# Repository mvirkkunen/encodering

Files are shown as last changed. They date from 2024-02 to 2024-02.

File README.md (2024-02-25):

encodering (unfinished - the firmware for one has never even been run)
======================================================================

Yet another LED ring for encoders.

Features (once finished):

- LEDs in a ring (30 by default - but the LED layout is autogenerated)
- Handles encoder signals, presents simple counter register
- Multiple styles of ring display, automatically updated based on counter
- I2C based communication saving pins on your microcontroller
- Interrupt output pin
- Analog voltage output for simulated potentiometer

I2C protocol
------------

Write access:

- Write: [register] [data] [data...]

Read access:

- Write: [register]
- Read: [data] [data...]

Register pointer is auto-incremented.

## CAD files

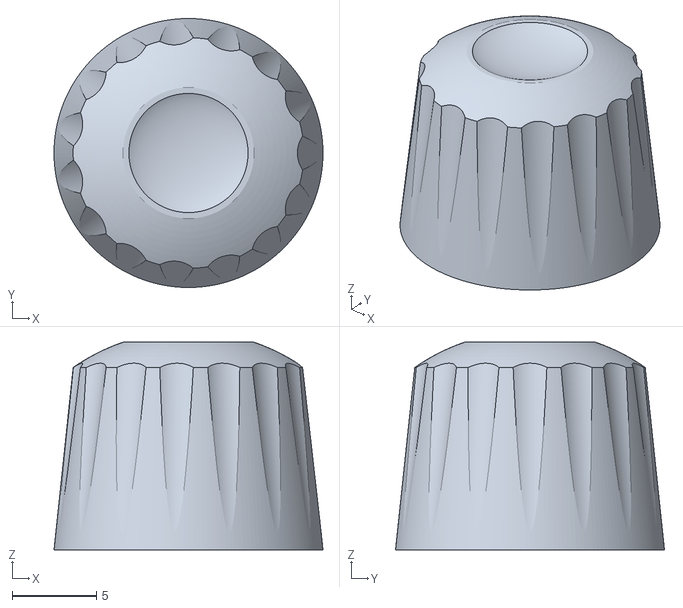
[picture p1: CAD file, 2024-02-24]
knob.stl
16.0 x 16.0 x 12.3

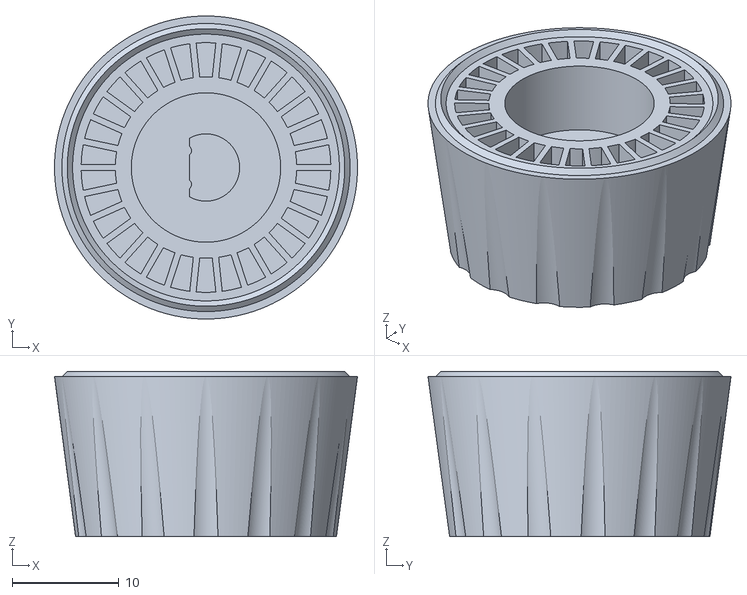
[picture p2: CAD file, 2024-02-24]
led_knob.stl
28.4 x 28.4 x 15.5

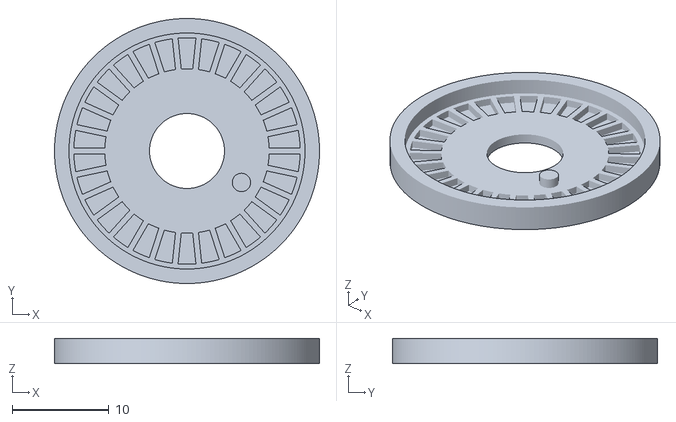
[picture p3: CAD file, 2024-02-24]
cover.stl
27.4 x 27.4 x 2.60

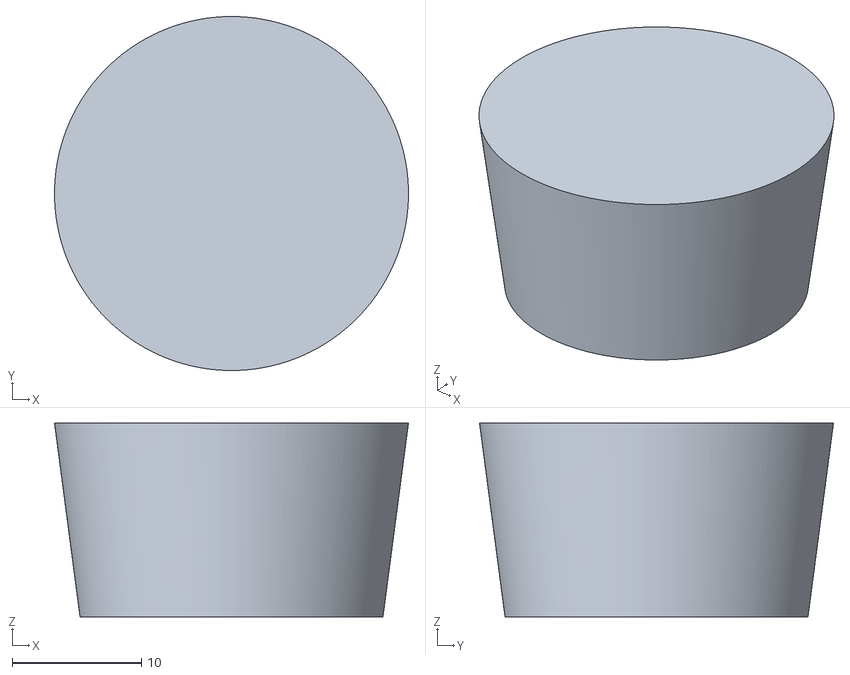
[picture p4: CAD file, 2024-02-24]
just_knob_envelope.stl
27.4 x 27.4 x 15.0

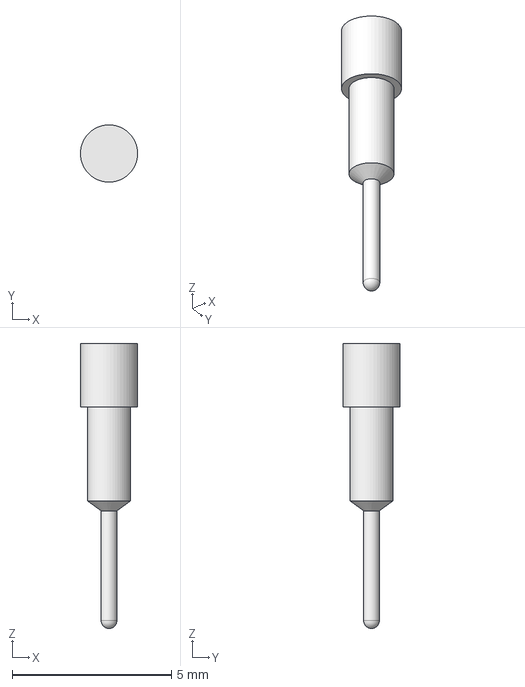
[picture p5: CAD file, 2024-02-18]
Connfly_DS-1006-11_No_Pin.FCStd
1.80 x 1.80 x 8.96 mm

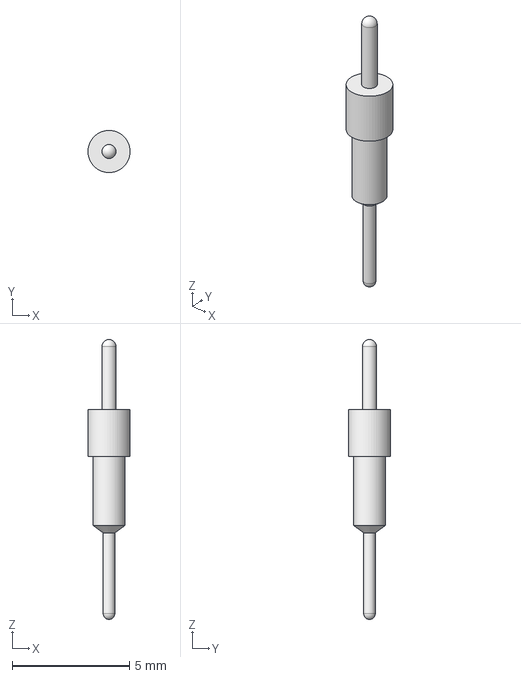
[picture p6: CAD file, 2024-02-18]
Connfly_DS-1006-11.FCStd
1.80 x 1.80 x 12.0 mm

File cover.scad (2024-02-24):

$fn = 180;

outer_diam = 24.4;
hole_diam = 7.75;
ring_r = 10;

alignment_hole_r = 6.5;
alignment_hole_a = 30;

wall_t = 1.5;

difference() {
  union() {
    difference() {
      cylinder(d=outer_diam + wall_t * 2, h=1 + 1.6);
      translate([0, 0, 0.25]) cylinder(d=outer_diam - 1, h=10);
      translate([0, 0, 1]) cylinder(d=outer_diam, h=10);
    }
    for (a = [0 : 360/30 : 360]) {
      rotate([0, 0, a]) translate([0, -0.3, 0]) cube([outer_diam/2, 0.6, 1]);
    }
    cylinder(r=ring_r - 1.5, h=1);
    rotate([0, 0, -alignment_hole_a]) translate([alignment_hole_r, 0, 0]) cylinder(d=1.9, h=1+1);
  }
  translate([0, 0, -1]) cylinder(d=hole_diam, h=10);
}

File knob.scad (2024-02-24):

$fn = 180;

diam = 16;
angle = 6;
height = 13;
knurls = 15;
knurl_r = 2.0;
knurl_angle = 8.0;
knurl_z = -0.3;
cap_r = 12;

shaft_d = 6.0 + 0.3;
shaft_d_t = 4.5;

d_interference = 0.2;

module knob() {
  intersection() {
    difference() {
      union() {
        difference() {
          cylinder(d1=diam, d2=diam - tan(angle) * height * 2, h=height);
          for (i = [0 : knurls]) {
            rotate([0, 0, 360/knurls * i])
              translate([diam/2 + knurl_r - -0.1, 0, knurl_z])
                rotate([0, -knurl_angle, 0]) cylinder(r=knurl_r , h=height*2);
          }
          
          translate([0, 0, -0.01]) difference() {
            cylinder(d=shaft_d, h=height - 2);
            translate([-shaft_d/2+shaft_d_t + d_interference, -shaft_d, -0.01])
              cube([shaft_d, shaft_d * 2, height]);
          }
        }
        
        translate([-shaft_d/2+shaft_d_t + 0.5, -shaft_d * 0.25, 0]) cylinder(d=1, h=height);
        translate([-shaft_d/2+shaft_d_t + 0.5, +shaft_d * 0.25, 0]) cylinder(d=1, h=height);
      }
      
      translate([0, 0, -0.1]) cylinder(d=diam - 3, h=4);
      
      translate([0, 0, height]) scale([4, 4, 1.4]) sphere(r=1);
      
      translate([0, 0, height - 0.65]) cylinder(d=diam, h=height);
    }
    hull() {
      translate([0, 0, height - cap_r]) sphere(r=cap_r);
      translate([0, 0, -height*2]) sphere(r=cap_r);
    }
  }
}

knob();

//intersection() { knob(); translate([-50, 0, -50]) cube([100, 100, 100]);  }

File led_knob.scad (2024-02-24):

$fn = $preview ? 45: 180;
E = 0.001;

module pcb_assembly() {
  color("green") translate([0, 0, -4.7 -1.6]) {
    difference() {
      rotate([0, 180, 0]) import("pcb_assembly.stl", convexity=5);
      /*translate([0, 0, -20]) union() {
        cylinder(d = 30, h=20 + 4.5+1.6);
        cylinder(d = 8, h=50);
      }*/
      translate([0, 0, 19]) cylinder(d=40, h=50);
    }
  }
  
  color("grey") translate([0, 0, 1.2]) {
    difference() {
      cylinder(d=11, h=2, $fn=6);
      translate([0, 0, -E]) cylinder(d=7.75, h=3);
    }
  }
}

leds = 30;
angle_step = 360 / leds;
outer_diam = 24 + 0.4;
hole_diam = 7.25;
ring_r = 10;
wall_t = 2;
led_h = 1.3;
knob_height = 15;
mizo_r = outer_diam * 0.5 + 0.8;

module led_separators(h) {
  for (a = [0 : angle_step : 360]) {
    rotate([0, 0, a]) translate([0, -0.3, 0]) cube([outer_diam/2, 0.6, h]);
  }
}

module plate() {
  alignment_hole_r = 6.5;
  alignment_hole_a = 30;

  difference() {
    union() {
      translate([0, 0, -1.6]) difference() {
        cylinder(d=outer_diam + wall_t * 2, h=led_h + 1.6);
        translate([0, 0, -E]) cylinder(d=outer_diam - 1, h=10);
      }
      cylinder(r=ring_r - 1.5, h=led_h);
      led_separators(led_h);
      
      rotate([0, 0, alignment_hole_a])
        translate([alignment_hole_r, 0, -1.2]) cylinder(d=1.9, h=1.2);
    }
    
    translate([0, 0, -1]) cylinder(d=hole_diam, h=10);
    
    translate([0, 0, 1.6])
      rotate_extrude()
        translate([mizo_r, 0])
          polygon([[-1, 0], [1, 0], [0, -1]]);
  }
}

module knob_envelope(d=0) {
  angle = 7.5;
  
  diam = outer_diam + wall_t * 2 + d;
  dd = tan(angle) * knob_height;
  cylinder(d1=diam, d2=diam - dd * 2, h=knob_height);
}

module knob() {
  diam = outer_diam + wall_t * 2;
  height = knob_height;
  knurls = 15;
  knurl_r = 2.0;
  knurl_angle = 5;
  knurl_z = -10.0;

  shaft_d = 6.0 + 0.3;
  shaft_d_t = 4.5;

  d_interference = 0.2;
  
  difference() {
    union() {
      difference() {
        union() {
          difference() {
            knob_envelope();
            translate([0, 0, -E]) cylinder(d=outer_diam - 1, h=$preview ? height + 1 : height - 0.24 + E);
          }
      
          led_separators(height);
          cylinder(r=ring_r - 1.5, h=height);
        }
        
        translate([0, 0, -0.01]) difference() {
          cylinder(d=shaft_d, h=height - 1);
          translate([-shaft_d/2+shaft_d_t + d_interference, -shaft_d, -0.01])
            cube([shaft_d, shaft_d * 2, height]);
        }
      }
      
      translate([-shaft_d/2+shaft_d_t + 0.5, -shaft_d * 0.25, 0]) cylinder(d=1, h=height);
      translate([-shaft_d/2+shaft_d_t + 0.5, +shaft_d * 0.25, 0]) cylinder(d=1, h=height);
      
      translate([0, 0, 0.5])
        rotate_extrude()
          translate([mizo_r, 0])
            polygon([[-1, 0], [1, 0], [0, -1]]);
    }
    
    translate([0, 0, -0.1]) cylinder(d=14, h=7);
    
    for (i = [0 : knurls]) {
      rotate([0, 0, 360/knurls * i + angle_step / 2])
        translate([diam/2 + knurl_r - -0.1, 0, knurl_z])
          rotate([0, -knurl_angle, 0]) cylinder(r=knurl_r , h=height*2);
    }
  }
}

module cutter() {
  translate([-50, 1, -50]) cube([100, 100, 100]);
}

if ($preview) {
  render() intersection() { cutter(); plate(); }
  intersection() { cutter(); translate([0, 0, 1.4]) rotate([0, 0, 180]) knob(); }

  pcb_assembly();
} else {
  //translate([outer_diam + 5, 0, led_h]) rotate([0, 180, 0]) plate();
  translate([0, 0, knob_height]) rotate([0, 180, 0]) knob();
  //translate([0, 0, knob_height]) rotate([0, 180, 0]) knob_envelope(-1);
}

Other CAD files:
just_knob.stl

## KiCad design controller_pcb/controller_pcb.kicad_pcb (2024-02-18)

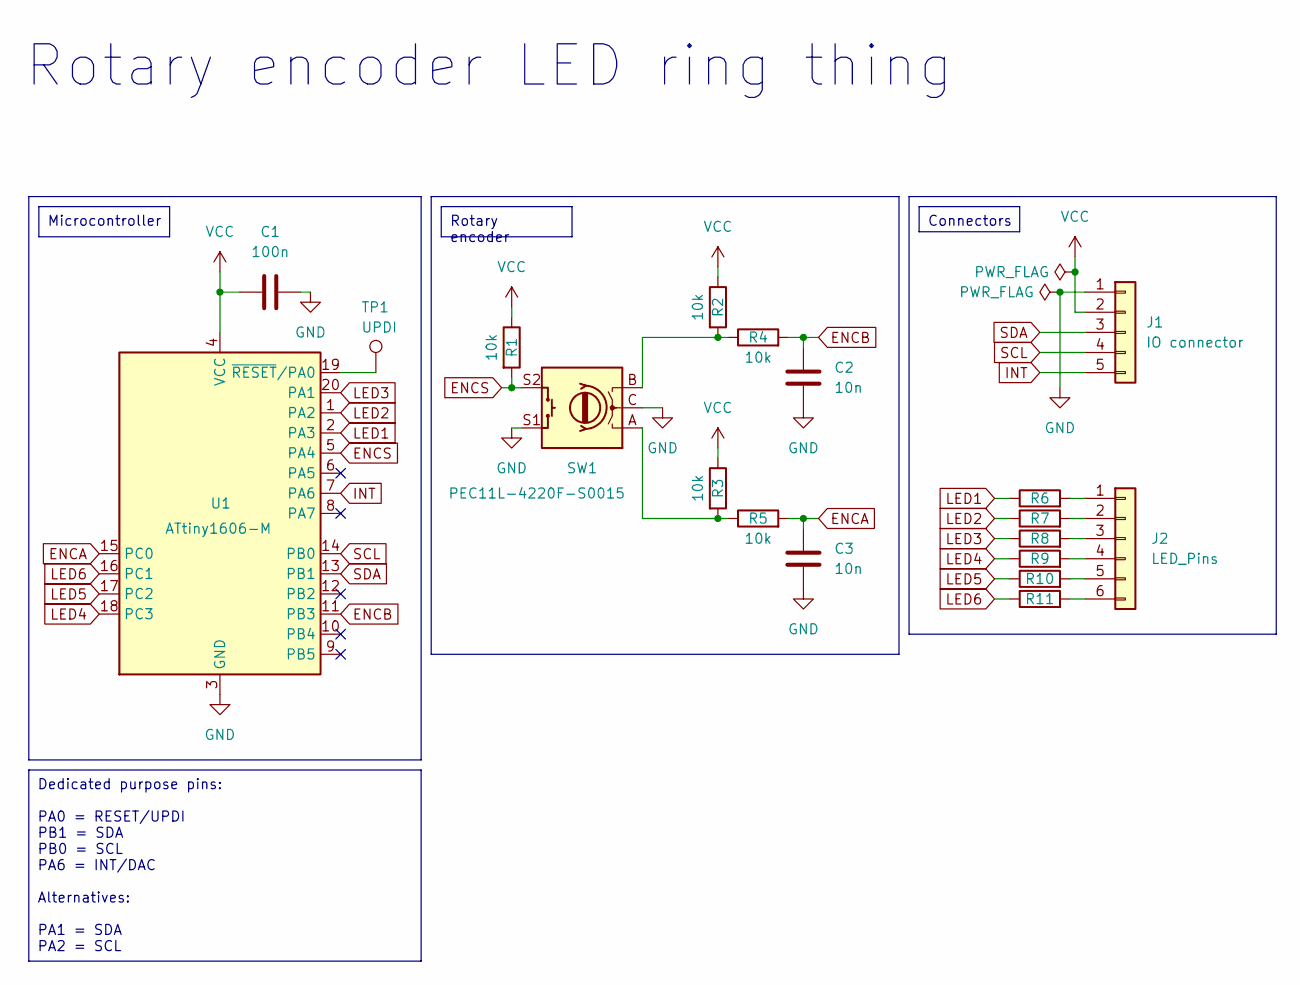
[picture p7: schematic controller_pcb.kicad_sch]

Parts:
C1: 100n; C_0603_1608Metric; LCSC C14663
C2, C3: 10n; C_0603_1608Metric; LCSC C57112
J1: IO connector; Project_PinHeader_1x05_P2.54mm_Vertical
J2: LED_Pins; Mounting_Hole_Pattern
R1, R2, R3, R4, R5: 10k; R_0603_1608Metric; LCSC C25804
R6, R7, R8, R9, R10, R11: 20ohm; R_0603_1608Metric; LCSC C22950
SW1: PEC11L-4220F-S0015; Project_RotaryEncoder_Bourns_Vertical_PEC12R-3x17F-Sxxxx
TP1: UPDI; TestPoint_Pad_D1.0mm
U1: ATtiny1606-M; Project_ATTINY1616_VQFN-20-1EP_3x3mm_P0.4mm_EP1.7x1.7mm; LCSC C507118

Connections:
ENCA: C3.2, R5.2, U1.15 (PC0)
ENCB: C2.2, R4.2, U1.11 (PB3)
ENCS: R1.2, SW1.S2, U1.5 (PA4)
GND: C1.2, C2.1, C3.1, J1.1, SW1.C, SW1.S1, U1.3 (GND), U1.21 (GND)
INT: J1.5, U1.7 (PA6)
LED1: R6.1, U1.2 (PA3)
LED2: R7.1, U1.1 (PA2)
LED3: R8.1, U1.20 (PA1)
LED4: R9.1, U1.18 (PC3)
LED5: R10.1, U1.17 (PC2)
LED6: R11.1, U1.16 (PC1)
unnamed: J2.1, R6.2
unnamed: J2.2, R7.2
unnamed: J2.3, R8.2
unnamed: J2.4, R9.2
unnamed: J2.5, R10.2
unnamed: J2.6, R11.2
unnamed: R2.2, R4.1, SW1.B
unnamed: R3.2, R5.1, SW1.A
unnamed: TP1.1, U1.19 (~RESET/PA0)
SCL: J1.4, U1.14 (PB0)
SDA: J1.3, U1.13 (PB1)
VCC: C1.1, J1.2, R1.1, R2.1, R3.1, U1.4 (VCC)

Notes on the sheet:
Microcontroller
Dedicated purpose pins: PA0 = RESET/UPDI PB1 = SDA PB0 = SCL PA6 = INT/DAC Alternatives: PA1 = SDA PA2 = SCL
Rotary encoder
Connectors
Rotary encoder LED ring thing

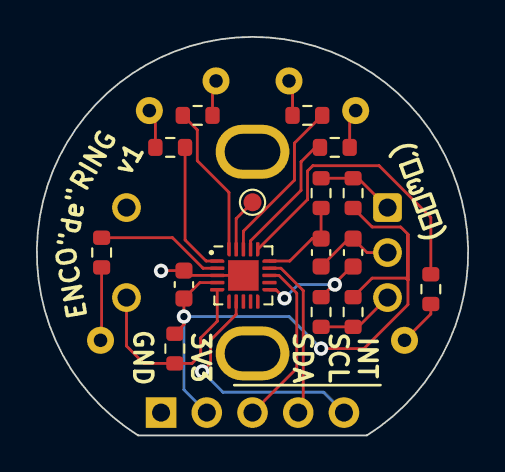
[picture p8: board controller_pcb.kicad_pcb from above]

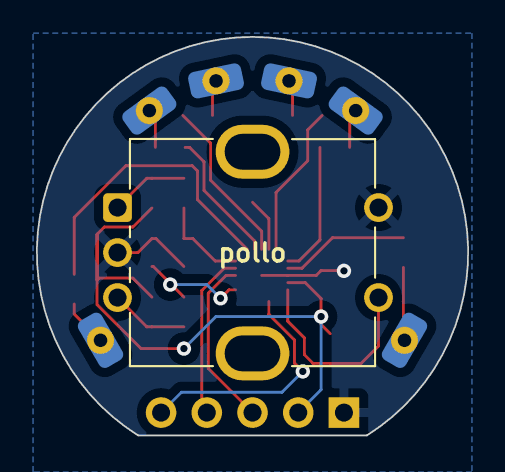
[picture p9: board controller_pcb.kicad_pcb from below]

Board: 2 copper layers, 24.0 x 22.1 mm, 19 parts (2 on the bottom side), 23 nets.

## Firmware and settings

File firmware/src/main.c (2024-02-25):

#include <avr/interrupt.h>
#include <avr/io.h>
#include <avr/sleep.h>
#include <util/atomic.h>
#include <stdbool.h>
#include <stdint.h>

#include "config.h"
#include "registers.h"
#include "leds.h"
#include "encoder.h"
#include "i2c.h"
#include "styles.h"

volatile uint16_t reg_counter;

volatile registers_t regs = REGS_INIT;

int main(void) {
    leds_init();
    encoder_init();
    i2c_init();
    i2c_enable();

    sei();

    while (true) {
        // Run main loop around 200 times a second

        while (led_cycles < LED_CYCLES_PER_SECOND / 200) { }
        led_cycles = 0;

        encoder_poll_button();

        int8_t delta;
        ATOMIC_BLOCK(ATOMIC_FORCEON) {
            delta = encoder_delta;
        }

        i2c_disable();
        reg_counter += delta;
        i2c_enable();

        uint8_t style = regs.config.style;
        if (style < STYLE_COUNT) {
            STYLES[style](delta);
        }
    }
}

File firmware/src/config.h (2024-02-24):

#ifdef UNITTEST
#include_next "config.h"
#else

#pragma once

#include "config_types.h"

#define I2C_ADDRESS 0x37
#define PIN_COUNT 6
#define LED_COUNT 30

#define PORT_ENCA    PORTC
#define BIT_ENCA     PIN0_bm
#define PINCTRL_ENCA PIN0CTRL

#define PORT_ENCB    PORTB
#define BIT_ENCB     PIN3_bm
#define PINCTRL_ENCB PIN3CTRL

#define PORT_ENCS    PORTA
#define BIT_ENCS     PIN4_bm

#define PORT_INT     PORTA
#define BIT_INT      PIN6_bm

extern const pin_def_t PIN_DEFS[PIN_COUNT];
extern const led_def_t LED_DEFS[LED_COUNT];

#ifdef CONFIG_C

const pin_def_t PIN_DEFS[PIN_COUNT] = {
    { 0, 1 << 3 },
    { 0, 1 << 2 },
    { 0, 1 << 1 },
    { 2, 1 << 3 },
    { 2, 1 << 2 },
    { 2, 1 << 1 },
};

const led_def_t LED_DEFS[LED_COUNT] = {
    { 0, 1, 0 },
    { 0, 2, 2 },
    { 0, 3, 4 },
    { 0, 4, 6 },
    { 0, 5, 8 },
    { 1, 0, 1 },
    { 1, 2, 10 },
    { 1, 3, 12 },
    { 1, 4, 14 },
    { 1, 5, 16 },
    { 2, 0, 3 },
    { 2, 1, 11 },
    { 2, 3, 18 },
    { 2, 4, 20 },
    { 2, 5, 22 },
    { 3, 0, 5 },
    { 3, 1, 13 },
    { 3, 2, 19 },
    { 3, 4, 24 },
    { 3, 5, 26 },
    { 4, 0, 7 },
    { 4, 1, 15 },
    { 4, 2, 21 },
    { 4, 3, 25 },
    { 4, 5, 28 },
    { 5, 0, 9 },
    { 5, 1, 17 },
    { 5, 2, 23 },
    { 5, 3, 27 },
    { 5, 4, 29 },
};

#endif

#endif

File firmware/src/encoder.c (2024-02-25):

#include <avr/interrupt.h>
#include <avr/io.h>
#include <stdbool.h>

#include "config.h"
#include "encoder.h"
#include "registers.h"
#include "unittest.h"

volatile int8_t encoder_delta = 0;

// ENCA = PC0
// ENCB = PB3
// ENCS = PA4

void encoder_init(void) {
    PORT_ENCA.PINCTRL_ENCA = PORT_ISC_BOTHEDGES_gc;
    PORT_ENCB.PINCTRL_ENCB = PORT_ISC_BOTHEDGES_gc;
}

void encoder_poll_button(void) {
    static bool prev_held = 0;

    bool held = PORT_ENCS.IN & BIT_ENCS;

    regs.status = (
        (held ? STATUS_BUTTON_HELD : 0)
        | ((held && !prev_held) ? STATUS_BUTTON_PRESSED : 0)
        | ((!held && prev_held) ? STATUS_BUTTON_RELEASED : 0)
    );
}

ISR(PORTA_PORT_vect) {
    uint8_t event = (
        0
        | !!(PORT_ENCA.IN & BIT_ENCA) << 3
        | !!(PORT_ENCB.IN & BIT_ENCB) << 2
        | !!(PORT_ENCA.INTFLAGS & BIT_ENCA) << 1
        | !!(PORT_ENCB.INTFLAGS & BIT_ENCB) << 0
    );

    switch (event) {
        case 0b1010:
        case 0b1101:
        case 0b0110:
        case 0b0001:
            encoder_delta++;
            break;
        case 0b0101:
        case 0b1110:
        case 0b1001:
        case 0b0010:
            encoder_delta--;
            break;
    }

    PORT_ENCB.INTFLAGS &= ~BIT_ENCB;
    PORT_ENCA.INTFLAGS &= ~BIT_ENCA;
}

ISR(PORTB_PORT_vect, ISR_ALIASOF(PORTA_PORT_vect));
ISR(PORTC_PORT_vect, ISR_ALIASOF(PORTA_PORT_vect));

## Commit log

2024-02-03 More schematic parsing and serializing bits
2024-02-05 Initial hardware
    [encodering.kicad_pcb, encodering.kicad_sch, untitled.kicad_sch]
2024-02-05 Started PCB stuff
2024-02-10 LED ring generator 2.0 + kigen fixes
    [controller_pcb.kicad_pcb, controller_pcb.kicad_sch, encodering.kicad_pcb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]
2024-02-10 Loadsa updates
    [controller_pcb.kicad_pcb, controller_pcb.kicad_sch]
2024-02-11 Almost done
    [controller_pcb.kicad_pcb, controller_pcb.kicad_sch]
2024-02-11 More tweaks
    [controller_pcb.kicad_pcb]
2024-02-11 Cool bicolor LED support
2024-02-17 Kicadet links
2024-02-18 v1 for manufacturing
    [Connfly_DS-1006-11.FCStd, Connfly_DS-1006-11_No_Pin.FCStd, controller_pcb.kicad_pcb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]
2024-02-18 ACTUAL manufactured version
    [controller_pcb.kicad_pcb, controller_pcb.kicad_sch]
2024-02-24 LED stuff
2024-02-24 HW stuff
    [cover.scad, cover.stl, just_knob.stl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]
2024-02-24 Implement encoder button, LED styles
2024-02-24 Generate pin config
2024-02-24 Generate LED schedules outside of ISR
2024-02-24 Add simple unit testing framework
2024-02-25 Maybe a working encoder
2024-02-25 I2C tests
